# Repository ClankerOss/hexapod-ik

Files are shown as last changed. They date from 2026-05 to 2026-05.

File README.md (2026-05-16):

# hexapod-ik

Robotic hexapod leg with a full 3-DOF inverse kinematics solver,
running on an Arduino in C++.

Type a target coordinate (X, Y, Z) over Serial and the leg tip
moves precisely to that position — joint angles solved in real time.

## Hardware

| Component | Details |
|---|---|
| Microcontroller | Arduino |
| Servos | MG995 (× 3) — provided by ETH Student Project House |
| Material | PETG (3D printed, chosen for structural stability) |
| Joints | Coaxial · Femur · Tibia |
| Screws | M4 × 20mm hex socket cap screws (Allen head) |

## Link lengths

| Segment | Length |
|---|---|
| Coaxial (l) | 50 mm |
| Femur (a) | 100 mm |
| Tibia (b) | 150 mm |

## CAD files

All parts designed for 3D printing in PETG.

| File | Description |
|---|---|
| `Connector_to_body.stl` | Mounts the leg assembly to the body |
| `Connector_to_Servo2.stl` | Interface between coaxial and femur servo |
| `Foot.stl` | Leg tip / contact point |
| `Joint_1_to_2.stl` | Coaxial to femur joint |
| `Joint_2_to_3.stl` | Femur to tibia joint |
| `Torque_1_to_2.stl` | Torque transfer coaxial → femur |
| `Torque_2_to_3.stl` | Torque transfer femur → tibia |
| `Assembly.stl` | Full assembled leg — shows how all parts fit together and what the finished leg should look like |

## Arduino files

### `InverseKinematics.ino`
Base IK solver. Reads X Y Z from Serial, computes joint angles
using 3-DOF geometric inverse kinematics, and drives all three
servos. Angles clamped to physical servo limits (0–180°).

### `InverseKinematicsConst.ino`
Extended version with mechanical constraint handling. Adds
dynamic range adjustment for the femur servo (servo2) when
the tibia angle exceeds 90° — prevents physical collision
between leg segments. Prints a warning to Serial when a
constraint is triggered.

### `ServoSweepTest.ino`
Calibration and testing utility. Sweeps all three servos
smoothly through their full range of motion (min → max → min)
in a continuous loop. Use this to verify that all servos are
correctly wired and that the leg moves freely through its
full range without mechanical interference. Set `set_pos = 0`
to park all servos at 90° (neutral) for assembly alignment.

## Assembly notes

Most fasteners are M4 × 20mm hex socket cap screws (Allen head).
Have an M4 Allen key available before assembly. The PETG parts
are designed to accept the screws directly — no inserts required.

## Usage

1. Flash either `.ino` to your Arduino
2. Open Serial Monitor at 9600 baud
3. Enter coordinates: `100 50 -80`
4. The leg moves to that position

## Built with

C++ · Arduino · Servo.h · Geometric IK · PETG · MG995

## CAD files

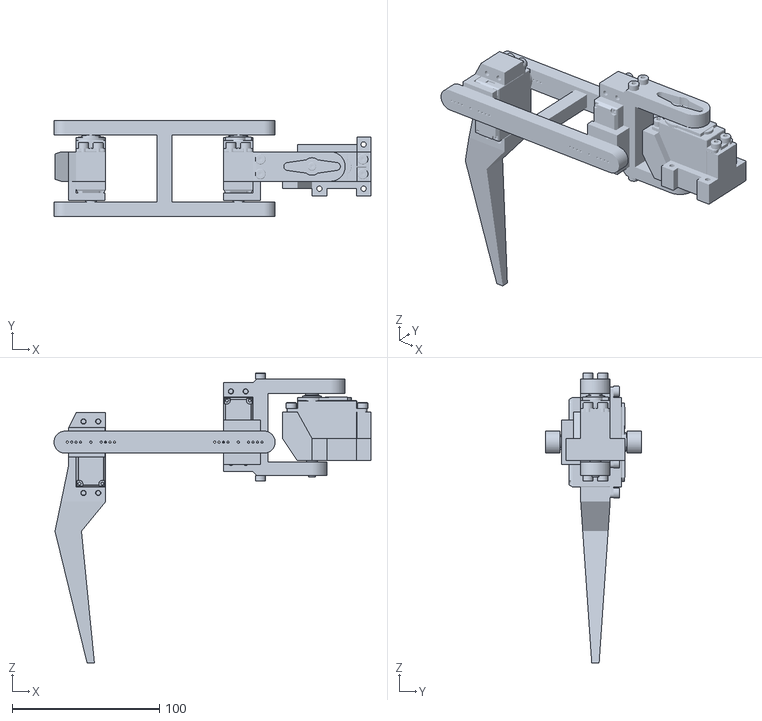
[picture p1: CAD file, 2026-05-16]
CAD/Assembly.stl
215.0 x 65.4 x 196.7

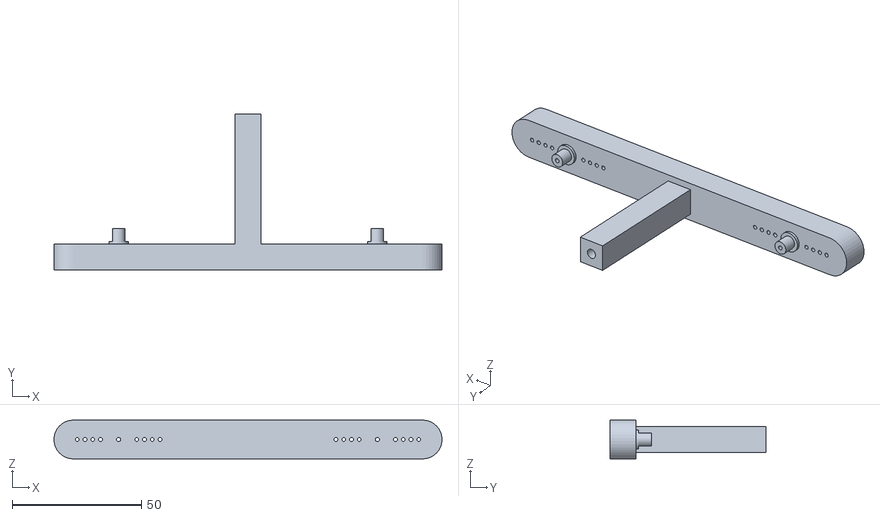
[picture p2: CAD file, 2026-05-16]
CAD/Joint_2_to_3.stl
149.9 x 60.4 x 15.0

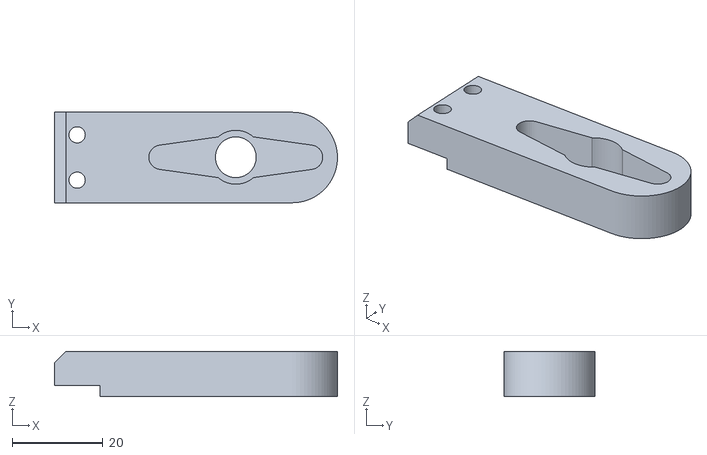
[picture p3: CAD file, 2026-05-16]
CAD/Torque 1 to 2.stl
62.5 x 20.0 x 10.00

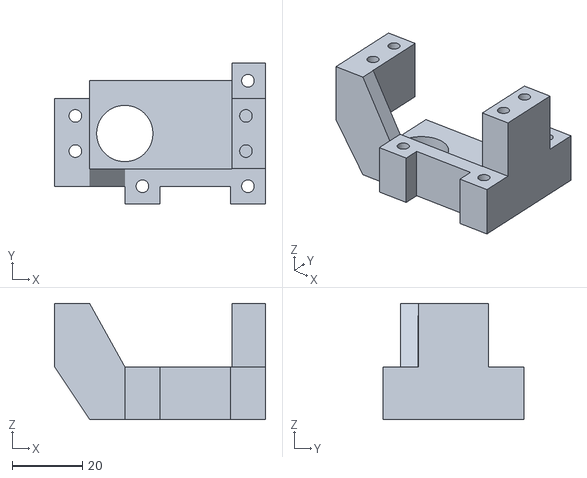
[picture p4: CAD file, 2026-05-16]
CAD/Connector_to_body.stl
60.0 x 40.0 x 33.0

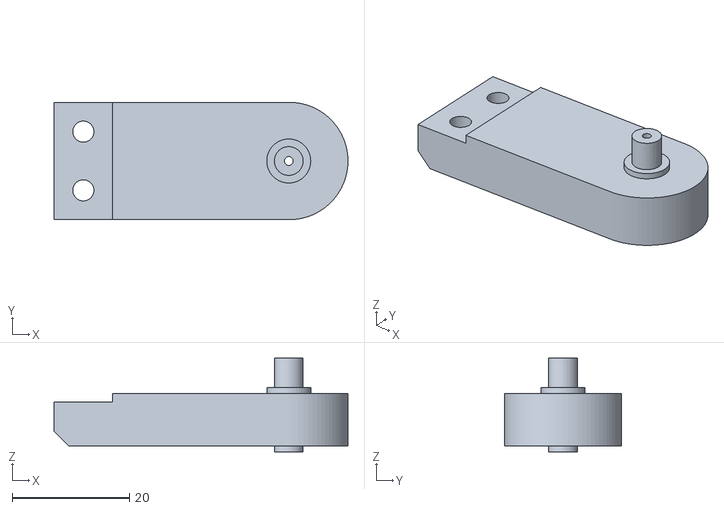
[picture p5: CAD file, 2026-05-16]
CAD/Joint_1_to_2.stl
50.1 x 20.0 x 16.0

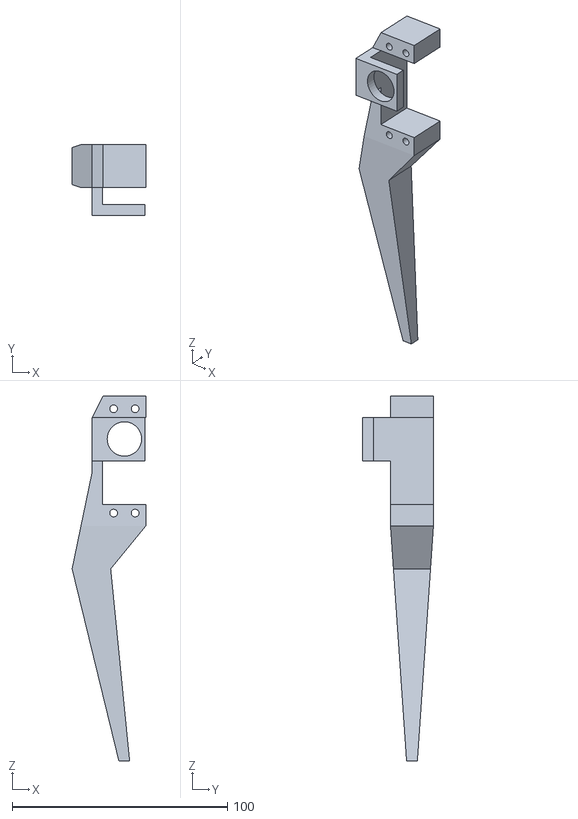
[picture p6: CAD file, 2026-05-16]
CAD/Foot.stl
34.3 x 33.0 x 169.8

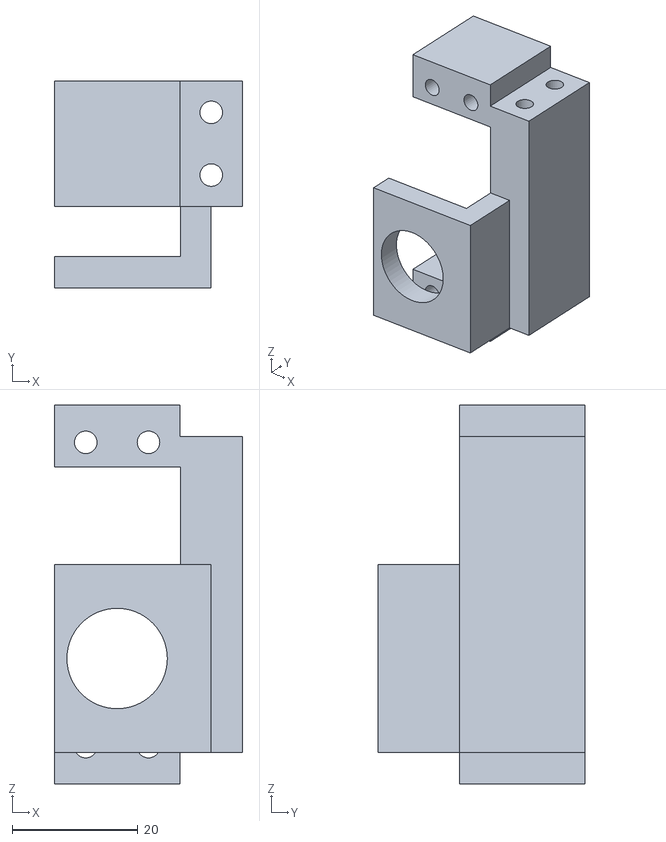
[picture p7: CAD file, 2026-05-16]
CAD/Connector_to_Servo2.stl
30.0 x 33.0 x 60.4

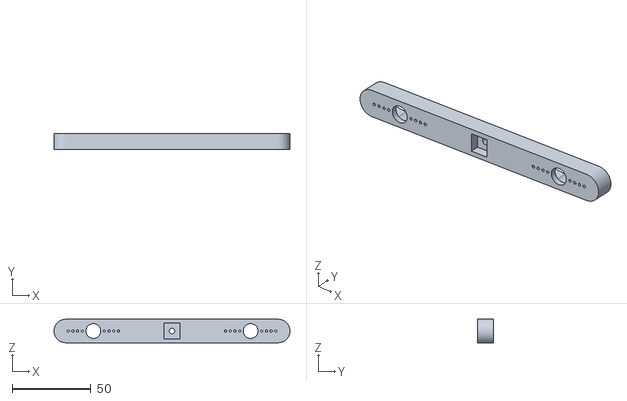
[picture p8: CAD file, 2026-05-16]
CAD/Torque_2_to_3.stl
150.0 x 10.0 x 15.0

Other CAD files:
CAD/Assembly.f3z

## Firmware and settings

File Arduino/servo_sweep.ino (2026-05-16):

#include <Servo.h>

Servo servo1;
Servo servo2;
Servo servo3;

int set_pos = 0;

// Individual limits
const int SERVO1_MIN = 0;
const int SERVO1_MAX = 180;

const int SERVO2_MIN = 0;
const int SERVO2_MAX = 180;   // Mechanically allowed, but logic will restrict below

const int SERVO3_MIN = 0;
const int SERVO3_MAX = 170;

// --- Constraint:
// If servo3 > 90° → servo2 must be >= 90°.
const int SERVO3_THRESHOLD = 90;
const int SERVO2_SAFE_MIN = 90;

void setup() {
  servo1.attach(3);
  servo2.attach(5);
  servo3.attach(6);

  if (set_pos == 0) {
    servo1.write(90);
    servo2.write(90);
    servo3.write(90); // max 170
  } else {
    servo1.write(SERVO1_MIN);
    servo2.write(SERVO2_MIN);
    servo3.write(SERVO3_MIN);
  }
}

void loop() {
  if (set_pos == 0) return;

  // Sweep forward
  for (int pct = 0; pct <= 100; pct++) {
    int pos1 = SERVO1_MIN + (SERVO1_MAX - SERVO1_MIN) * pct / 100;
    int pos2 = SERVO2_MIN + (SERVO2_MAX - SERVO2_MIN) * pct / 100;
    int pos3 = SERVO3_MIN + (SERVO3_MAX - SERVO3_MIN) * pct / 100;

    // Apply constraint:
    if (pos3 > SERVO3_THRESHOLD) {
      pos2 = max(pos2, SERVO2_SAFE_MIN);
    }

    servo1.write(pos1);
    servo2.write(pos2);
    servo3.write(pos3);
    delay(20);
  }

  delay(500);

  // Sweep backward
  for (int pct = 100; pct >= 0; pct--) {
    int pos1 = SERVO1_MIN + (SERVO1_MAX - SERVO1_MIN) * pct / 100;
    int pos2 = SERVO2_MIN + (SERVO2_MAX - SERVO2_MIN) * pct / 100;
    int pos3 = SERVO3_MIN + (SERVO3_MAX - SERVO3_MIN) * pct / 100;

    // Apply constraint:
    if (pos3 > SERVO3_THRESHOLD) {
      pos2 = max(pos2, SERVO2_SAFE_MIN);
    }

    servo1.write(pos1);
    servo2.write(pos2);
    servo3.write(pos3);
    delay(20);
  }

  delay(500);
}

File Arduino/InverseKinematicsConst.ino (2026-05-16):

#include <Servo.h>
#include <math.h>

Servo servo1;
Servo servo2;
Servo servo3;

// Link Lengths
const float a = 100; // Femur
const float b = 150; // Tibia (Foot)
const float l = 50;  // Coaxial

void setup() {
  Serial.begin(9600);
  servo1.attach(3); // Coaxial
  servo2.attach(5); // Femur
  servo3.attach(6); // Tibia (Foot)
  Serial.println("Enter X Y Z (eg., 100 100 100)");
}

void loop() {
  if (Serial.available()) {
    float x = Serial.parseFloat();
    float y = Serial.parseFloat();
    float z = Serial.parseFloat();
    delay(10);
    while (Serial.available()) Serial.read();
  
    // Inverse Kinematics
    float d = sqrt(x*x + y*y);
    float r = d - l;
    float c = sqrt(z*z + r*r);

    // Angles in degrees (your original formulas)
    float theta1 = atan2(y, x) * 180.0 / PI;
    float theta2 = atan2(r, -z) * 180.0 / PI + acos((a*a + c*c - b*b) / (2 * a * c)) * 180.0/PI;
    float theta3 = 180.0 - acos((a*a + b*b - c*c) / (2 * a * b)) * 180.0 / PI;

    Serial.print("Theta1: "); Serial.println(theta1);
    Serial.print("Theta2: "); Serial.println(theta2);
    Serial.print("Theta3: "); Serial.println(theta3);
    Serial.println("- - - - - - - - - -");

    // -------- Move the Servos (with mechanical constraint) --------
    
    // Basic clamp for servo1 and servo3
    float angle1 = constrain(theta1, 0, 180);
    float angle3 = constrain(theta3, 0, 180);

    // Default allowed range for servo2
    float servo2_min = 0;
    float servo2_max = 180;

    // Flag to detect if constraint actually clipped theta2
    bool constraintTriggered = false;

    // If servo3 (theta3) > 90°, servo2 must be between 90 and 190
    if (angle3 > 90) {
      servo2_min = 90;
      servo2_max = 190; // logical upper bound before final 0–180 clamp
    }

    float rawTheta2 = theta2; // store original IK result

    // Apply mechanical constraint range
    float angle2 = constrain(theta2, servo2_min, servo2_max);

    // Final hard clamp to real servo limits
    float finalAngle2 = constrain(angle2, 0, 180);

    // Detect if we actually clipped because of the constraint
    if (angle3 > 90 && (rawTheta2 < servo2_min || rawTheta2 > servo2_max)) {
      constraintTriggered = true;
    }

    if (constraintTriggered) {
      Serial.println("Mechanical constraint");
    }

    // Send to servos
    servo1.write(angle1);
    servo2.write(finalAngle2);
    servo3.write(angle3);
  }
}

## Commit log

2026-05-16 Rename Leg - Version 3.f3z to Assembly.f3z
    [Assembly.f3z, Leg - Version 3.f3z]
2026-05-16 Add screw specifications and repository structure
    Updated README to include screw specifications and repository structure.
